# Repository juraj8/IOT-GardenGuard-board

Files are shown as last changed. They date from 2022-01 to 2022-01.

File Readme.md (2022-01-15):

# Garden Guard





GardenGuard is an IOT type device created for collecting temperature data from multiple points in our garden. Main usecase for this data is to give alert for freezing weather in spring months, so user can take mitigation steps to prevent frost of the blooming fruit trees.

Freezing in spring months takes a lot of fruits from our garden. This is an attempt to hopefully get more fruits of our garden.  

## Features

- Uses multiple DS18x20 sensors to sample surrounding temperature.
- Solar and battery powered. Battery is charged wia solar panel, if battery is full, device only runs out of solar.  
- Battery voltage measurement.
- Battery should last over span of whole winter

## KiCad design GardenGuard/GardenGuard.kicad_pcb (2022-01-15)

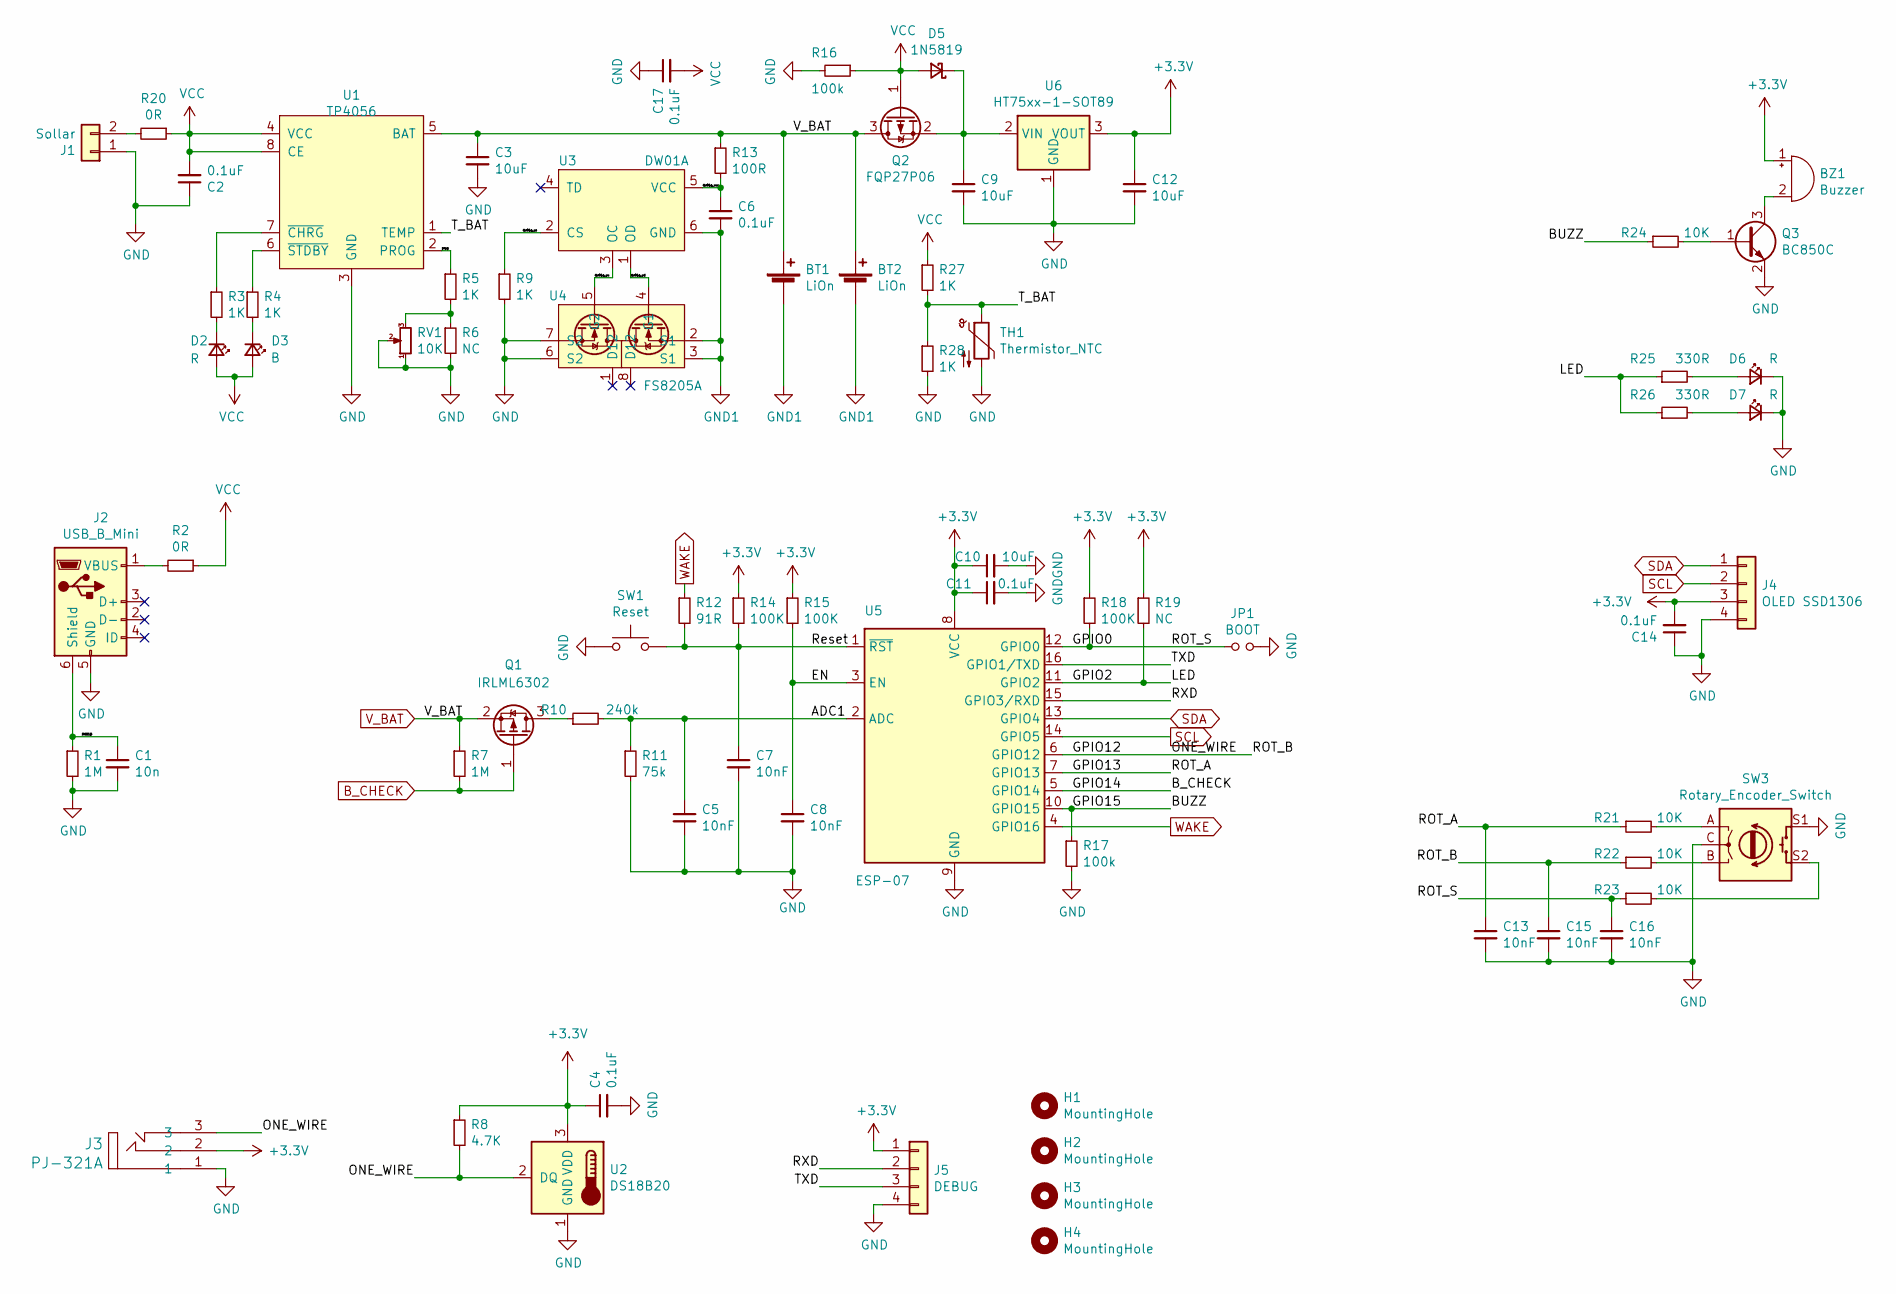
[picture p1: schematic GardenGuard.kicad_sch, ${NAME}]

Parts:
BT1, BT2: LiOn; BatteryHolder_Keystone_1042_1x18650
BZ1: Buzzer; Buzzer_12x9.5RM7.6
C1: 10n; C_0805_2012Metric_Pad1.18x1.45mm_HandSolder
C2, C17: 0.1uF; C_1206_3216Metric_Pad1.33x1.80mm_HandSolder
C3, C10: 10uF; C_1206_3216Metric_Pad1.33x1.80mm_HandSolder
C4, C6, C11, C14: 0.1uF; C_0805_2012Metric_Pad1.18x1.45mm_HandSolder
C5, C7, C8, C13, C15, C16: 10nF; C_0805_2012Metric_Pad1.18x1.45mm_HandSolder
C9, C12: 10uF; C_0805_2012Metric_Pad1.18x1.45mm_HandSolder
D2, D6, D7: R; LED_0805_2012Metric_Castellated
D3: B; LED_0805_2012Metric_Castellated
D5: 1N5819; D_SOD-123
H1, H2, H3, H4: MountingHole; MountingHole_3.2mm_M3_DIN965
J1: Sollar; ER-CON2.0-2P-SMD
J2: USB_B_Mini; USB_Micro-B_Amphenol_10118194_Horizontal
J3: PJ-321A
J4: OLED SSD1306; PinHeader_1x04_P2.54mm_Vertical
J5: DEBUG; PinHeader_1x04_P2.54mm_Vertical
JP1: BOOT; SolderJumper-2_P1.3mm_Open_RoundedPad1.0x1.5mm
Q1: IRLML6302; SOT-23_Handsoldering
Q2: FQP27P06; SOT-23_Handsoldering
Q3: BC850C; SOT-23_Handsoldering
R1, R7: 1M; R_0805_2012Metric_Pad1.20x1.40mm_HandSolder
R2, R20: 0R; R_0805_2012Metric_Pad1.20x1.40mm_HandSolder
R3, R4, R5, R9, R27, R28: 1K; R_0805_2012Metric_Pad1.20x1.40mm_HandSolder
R6, R19: NC; R_0805_2012Metric_Pad1.20x1.40mm_HandSolder
R8: 4.7K; R_0805_2012Metric_Pad1.20x1.40mm_HandSolder
R10: 240k; R_0805_2012Metric_Pad1.20x1.40mm_HandSolder
R11: 75k; R_0805_2012Metric_Pad1.20x1.40mm_HandSolder
R12: 91R; R_0805_2012Metric_Pad1.20x1.40mm_HandSolder
R13: 100R; R_0805_2012Metric_Pad1.20x1.40mm_HandSolder
R14, R15, R18: 100K; R_0805_2012Metric_Pad1.20x1.40mm_HandSolder
R16, R17: 100k; R_0805_2012Metric_Pad1.20x1.40mm_HandSolder
R21, R22, R23, R24: 10K; R_0805_2012Metric_Pad1.20x1.40mm_HandSolder
R25, R26: 330R; R_0805_2012Metric_Pad1.20x1.40mm_HandSolder
RV1: 10K; Potentiometer_Bourns_3224J_Horizontal
SW1: Reset; SW_SPST_B3U-3000P
SW3: Rotary_Encoder_Switch; RotaryEncoder_Alps_EC11E-Switch_Vertical_H20mm
TH1: Thermistor_NTC; R_Axial_DIN0204_L3.6mm_D1.6mm_P5.08mm_Horizontal
U1: TP4056; TP4056_SOP-8-PP
U2: DS18B20; TO-92_Inline
U3: DW01A; SOT-23-6
U4: FS8205A; TSSOP-8_4.4x3mm_P0.65mm
U5: ESP-07
U6: HT75xx-1-SOT89; SOT-89-3

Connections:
+3V3: BZ1.1 (-), C4.1, C10.1, C11.1, C12.1, C14.2, J3.2, J4.3, J5.1, R8.1, R14.1, R15.1, R18.1, R19.1, U2.3 (VDD), U5.8 (VCC), U6.3 (VOUT)
/ADC1: C5.1, R10.2, R11.1, U5.2 (ADC)
/BUZZ: R17.1, R24.1, U5.10 (GPIO15)
/EN: C8.1, R15.2, U5.3 (EN)
/GPIO0: C16.1, JP1.1, R18.2, R23.1, U5.12 (GPIO0)
/GPIO2: R19.2, R25.1, R26.1, U5.11 (GPIO2)
/GPIO12: C15.1, J3.3, R8.2, R22.1, U2.2 (DQ), U5.6 (GPIO12)
/GPIO13: C13.1, R21.1, U5.7 (GPIO13)
/RXD: J5.2, U5.15 (GPIO3/RXD)
/Reset: C7.1, R12.2, R14.2, SW1.2, U5.1 (~RST)
/SHIELD: C1.1, J2.6 (Shield), R1.1
/TXD: J5.3, U5.16 (GPIO1/TXD)
/T_BAT: R27.2, R28.1, TH1.1, U1.1 (TEMP)
/dw01a_cs: R9.1, U3.2 (CS)
/dw01a_oc: U3.3 (OC), U4.5 (G2)
/dw01a_od: U3.1 (OD), U4.4 (G1)
/dw01a_vcc: C6.1, R13.2, U3.5 (VCC)
/prog: R5.1, U1.2 (PROG)
B_CHECK: Q1.1 (G), R7.2, U5.5 (GPIO14)
GND: C1.2, C2.1, C3.2, C4.2, C5.2, C7.2, C8.2, C9.2, C10.2, C11.2, C12.2, C13.2, C14.1, C15.2, C16.2, C17.1, D6.1 (K), D7.1 (K), J1.1, J2.5 (GND), J3.1, J4.4, J5.4, JP1.2, Q3.2 (E), R1.2, R6.2, R9.2, R11.2, R16.2, R17.2, R28.2, RV1.1, RV1.2, SW1.1, SW3.C, SW3.S1, TH1.2, U1.3 (GND), U2.1 (GND), U4.6 (S2), U4.7 (S2), U5.9 (GND), U6.1 (GND)
GND1: BT1.2 (-), BT2.2 (-), C6.2, U3.6 (GND), U4.2 (S1), U4.3 (S1)
unnamed: BZ1.2 (+), Q3.3 (C)
unnamed: C9.1, D5.1 (K), Q2.2 (S), U6.2 (VIN)
unnamed: D2.1 (K), R3.2
unnamed: D3.1 (K), R4.2
unnamed: D6.2 (A), R25.2
unnamed: D7.2 (A), R26.2
unnamed: J1.2, R20.2
unnamed: J2.1 (VBUS), R2.2
unnamed: Q3.1 (B), R24.2
unnamed: R3.1, U1.7 (~CHRG)
unnamed: R4.1, U1.6 (~STDBY)
unnamed: R5.2, R6.1, RV1.3
unnamed: Q1.3 (D), R10.1
unnamed: R21.2, SW3.A
unnamed: R22.2, SW3.B
unnamed: R23.2, SW3.S2
SCL: J4.2, U5.14 (GPIO5)
SDA: J4.1, U5.13 (GPIO4)
VCC: C2.2, C17.2, D2.2 (A), D3.2 (A), D5.2 (A), Q2.1 (G), R2.1, R16.1, R20.1, R27.1, U1.4 (VCC), U1.8 (CE)
V_BAT: BT1.1 (+), BT2.1 (+), C3.1, Q1.2 (S), Q2.3 (D), R7.1, R13.1, U1.5 (BAT)
WAKE: R12.1, U5.4 (GPIO16)

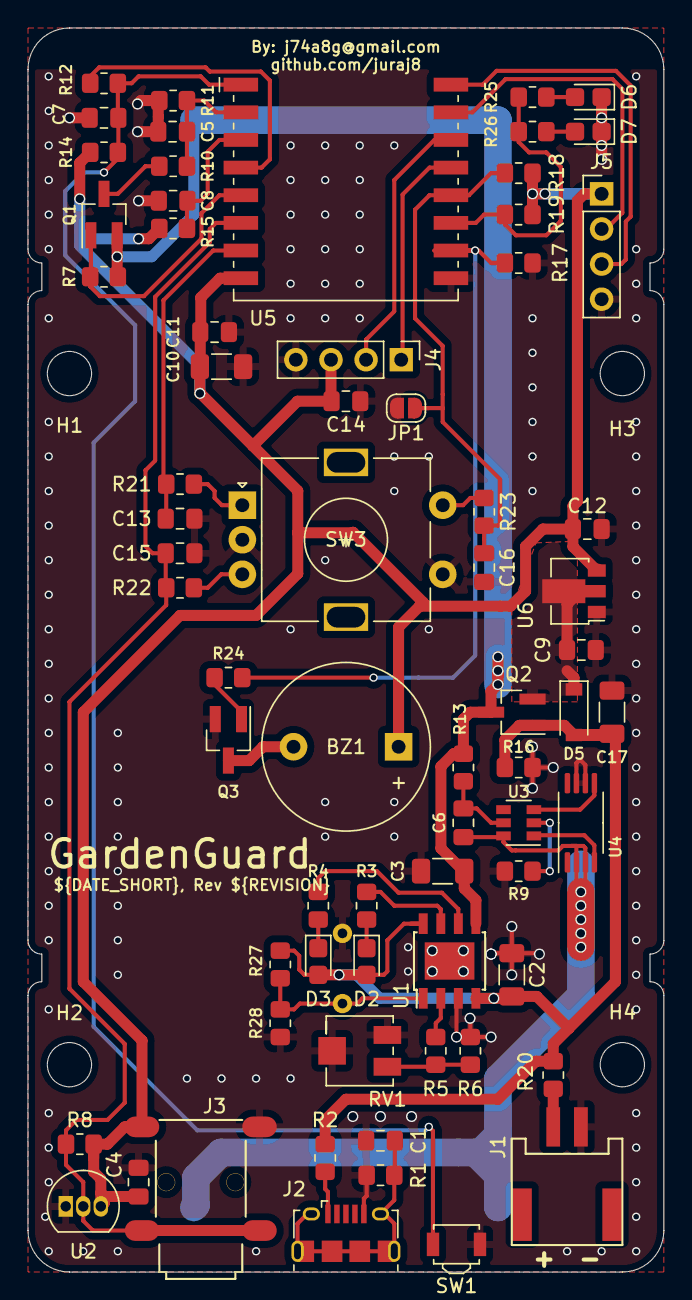
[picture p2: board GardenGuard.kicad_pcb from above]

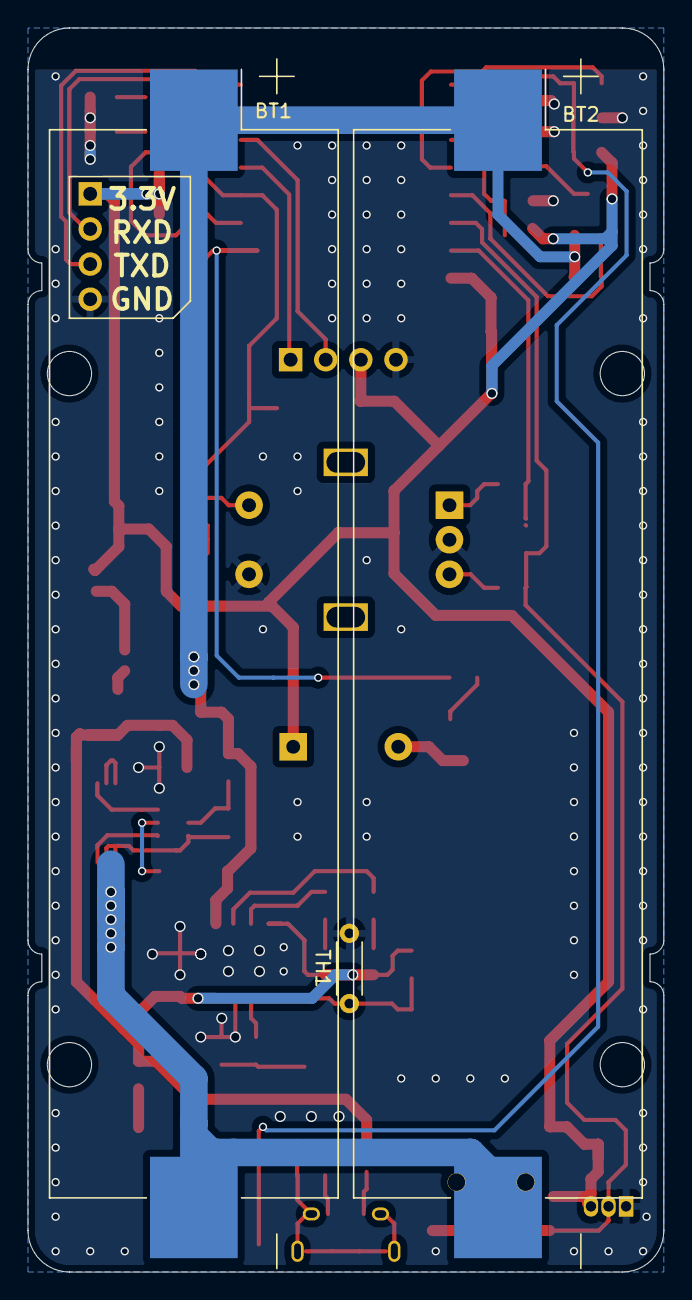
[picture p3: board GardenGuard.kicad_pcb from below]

Board: 2 copper layers, 46.0 x 90.0 mm, 76 parts (3 on the bottom side), 42 nets.

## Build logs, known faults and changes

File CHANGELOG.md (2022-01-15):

# Changelog

## v1.1.0 (15.01.2022)

- upgrate to kicad 6.
- update component values.

## v1.0.0 (25.07.2021)

- initial release.
- power managment integrated (battery, sollar, usb)
- combine two device versions in one board. onle board as smapling device, second as UI interface.
- temperature measurments only.
- battery voltage measurment using ADC.
- UI usin OLED display, indication LEDs and rotarry encoder as input.

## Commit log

2021-05-09 Add empty KiCAD project files.
    [GardenGuard.kicad_pcb, GardenGuard.sch]
2021-05-09 Add programer schematic.
    [GardenGuard.sch, programmer.sch]
2021-07-19 Added powersupply stages
    [GardenGuard.kicad_pcb, GardenGuard.sch, programmer.sch]
2021-07-21 shematic finished
    [GardenGuard.sch]
2021-07-22 Updated packages, start layout
    [GardenGuard.kicad_pcb, GardenGuard.sch, programmer.sch]
2021-07-24 layout done
    [GardenGuard.kicad_pcb, GardenGuard.sch]
2021-07-25 Release v1.0.0 - board finished
    [GardenGuard.kicad_pcb, GardenGuard.sch]
2022-01-15 Release v1.1.0 - update component values - cleanup
    [GardenGuard.kicad_pcb, GardenGuard.kicad_sch, GardenGuard.sch]
